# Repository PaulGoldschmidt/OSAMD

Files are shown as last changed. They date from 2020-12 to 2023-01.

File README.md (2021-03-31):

# Wie man ein Luftqualitätssensor mit einem niedrigen Budget baut: Das OSAMD-Projekt
Hohe Luftqualität ist wichtig. Eigentlich schon immer, denn in besserer Luft kann man sich länger konzentrieren. Grade in der Schule ist das Thema doch jetzt wichtiger denn je, denn dank COVID-19 müssen in vielen Schulen Deutschlands regelmäßig Lüftungspausen eingelegt werden. Was ansich gut ist, wird im Winter von Tag zu Tag schwieriger umzusetzen: Das kalte Klima und die Heizungen im Klassenzimmer führen so täglich einen Kampf um die Lufttemperatur, bei der die Heizung nur unter erheblicher Wärmeabgabe die Luft aufwärmen kann, was zu enormen Steigerungen der Heizungskosten und einem erhöhtem CO2-Ausstoß führt.

Deshalb habe ich mich dafür entschlossen, ein Luftqualitätsmessgerät zu entwickeln, welches mit niedrigen Teilkosten (circa 7-10 Euro/Einheit) die Luft in Klassenzimmern überwachen kann und eine Warnung abgibt, wenn die Luftqualität kritisch schlecht ist. Der Name dieses Projekts, OSAMD, steht für "Open-Source Air-Monitoring Device", also eine quelloffene Lösung zur Überwachung der Luftqualität.
Eine Anleitung zum Selbstbau dieses Projekts liegt im Ordner "0_Documentation", die Hardwareteile im Ordner "1_Hardware" und die benötigte Software im Ordner "2_Software".

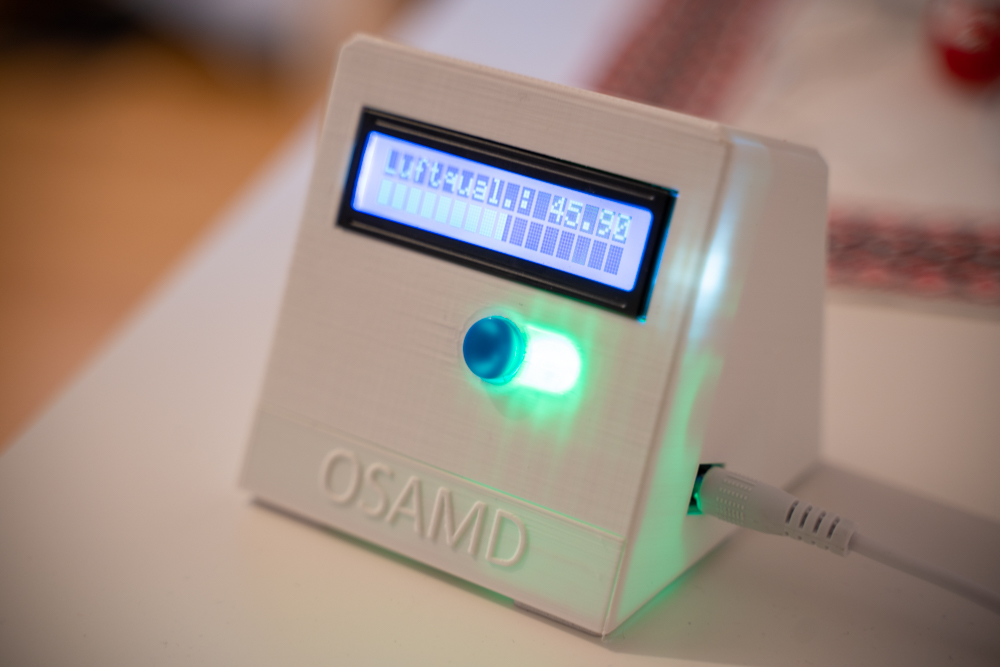
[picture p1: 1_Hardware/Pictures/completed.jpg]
Das fertige OSAMD-Projekt

[So wurde übrigens das Gehäuse designed](https://www.youtube.com/watch?v=d4DvKm7_OzI)

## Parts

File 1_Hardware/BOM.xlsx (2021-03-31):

BOM: OSAMD-Projekt
 | Teil Nr. | Bezeichnung | Teilnummer | Anzahl | Preis | Anmerkung | Link
 | 1 | Luftqualitätssensor | MQ-135 Module | 1 | 1.00 € |  | https://de.aliexpress.com/item/32905811669.html
 | 2 | Microcontroller | Arduino Nano | 1 | 1.60 € | Anschlusstyp ist nicht relevant, solange ein passendes Kabel vorhanden ist. (Ich empfehle Micro-USB) | https://de.aliexpress.com/item/32241679858.html
 | 3 | LCD-Display | 1602 LCD Display | 1 | 0.80 € | Es kann auch direkt ausgwählt werden, dass ein I2C-Wandler vorinstalliert werden soll. Dies spart Arbeit und Versandkosten. | https://de.aliexpress.com/item/32649621944.html
 | 4 | I2C-Wandler | PCF8574 | 1 | 0.50 € |  | https://de.aliexpress.com/item/32262710755.html
 | 5 | Knopf | 12x12x7 mm | 1 | 0.05 € | Preis für 20 Stück unter 0,8 Euro | https://de.aliexpress.com/item/32912422770.html
 | 6 | RGB-LED | Common Anode RGB LED (5mm) | 1 | 0.03 € | Preis für 100 Stück circa 3 Euro | https://de.aliexpress.com/item/32686524860.html
 | 7 | Stromanschluss | DC-005C-25A | 1 | 0.25 € |  | https://lcsc.com/product-detail/AC-DC-Power-Plugs-Receptacles_Korean-Hroparts-Elec-DC-005C-25A_C223903.html
 | 8 | Lautsprecher/Buzzer | 5V Piezo Summer | 1 | 0.10 € | Preis für 10 Stück unter einem Euro | https://de.aliexpress.com/item/32914327679.html
 | 9 | Widerstand 10 kOhm | 1/4 Watt Metallfilm | 2 | 0.01 € | Preis für 100 Stück circa 0,7 Euro | https://de.aliexpress.com/item/32315929780.html
 | 10 | Widerstand 180 Ohm | 1/4 Watt Metallfilm | 1 | 0.01 € | Preis für 100 Stück circa 0,7 Euro | https://de.aliexpress.com/item/32317099861.html
 | 11 | Widerstand 130 Ohm | 1/4 Watt Metallfilm | 1 | 0.01 € | Preis für 100 Stück circa 0,4 Euro | https://de.aliexpress.com/item/1005001649125832.html
 | 12 | Widerstand 120 Ohm | 1/4 Watt Metallfilm | 1 | 0.01 € | Preis für 100 Stück circa 0,7 Euro | https://de.aliexpress.com/item/32577107532.html
 | 13 | Leiterplatte | 1,6 mm, 2 Layer 85 * 70 mm FR4 PCB | 1 | 0.34 € | Preis für 5 Stück 1,69 Euro | https://jlcpcb.com/order
 | 14 | Stromkabel | USB zu DC 5,5 * 2,5mm Stromkabel | 1 | 0.83 € | Es gibt verschiende Längen und unterschiedliche Kabelfarben zur Auswahl, solange der Anschluss passt, ist diese Auswahl egal. | https://de.aliexpress.com/item/4000993209004.html
 | 15 | Versandpauschale | - | - | 4.00 € | - | -
 |  | ZUSAMMEN |  |  | 9.54 €
 | Hinweise: | Allgemein lohnt es sich, die Teile zu Vergleichen und zu schauen, wer zur Zeit die besten Teilpreise liefert.
 |  | Auch Sammelbestellungen lohnen sich sehr, so schafft man niedrigere Gesamtpreise und spart Versandkosten und CO2-Emissionen.

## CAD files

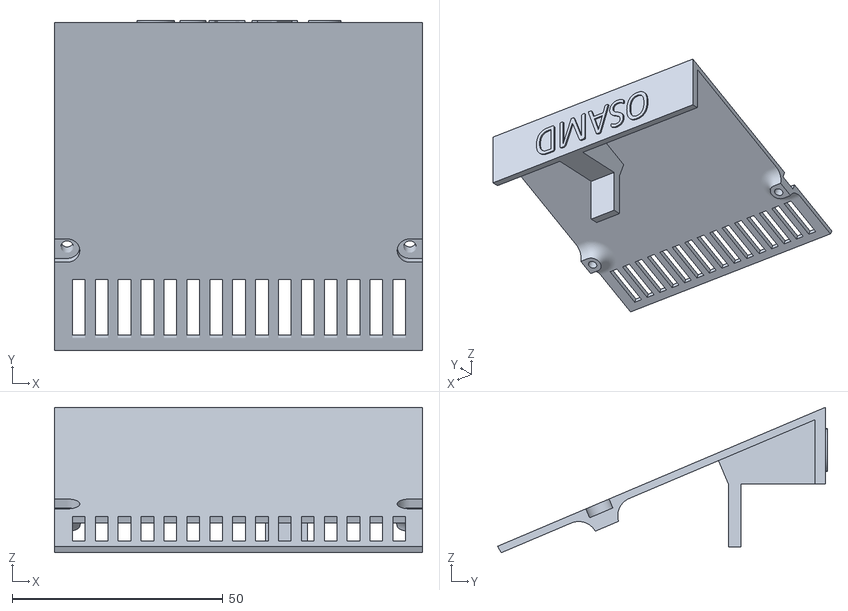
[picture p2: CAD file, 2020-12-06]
1_Hardware/Enclosure/Enclosure_PART-B.stl
87.2 x 78.2 x 34.5

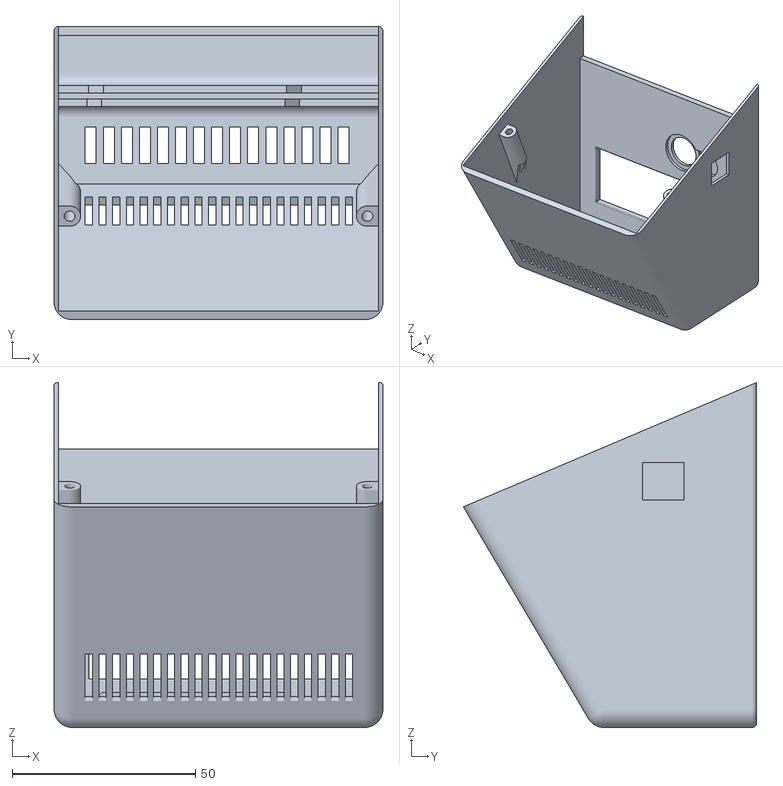
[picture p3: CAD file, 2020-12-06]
1_Hardware/Enclosure/Enclosure_PART-A.stl
89.8 x 80.1 x 94.2

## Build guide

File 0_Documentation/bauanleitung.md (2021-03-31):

# Wie man OSAMD bauen kann: Eine kleine Anleitung :bulb:
In diesem Dokument wird gezeigt, wie man sich die Luftqualitätsmessstation selber bauen kann. Viel Spaß beim bauen!
## Schritt 1: Vorbereitungen
Bevor mit dem Bauen begonnen wird, sollte sichergestellt werden, dass alle Teile und Werkzeuge zur Verfügung stehen.
Eine Materialliste (BOM, Bill of Materials) lässt sich [hier finden.](https://github.com/PaulGoldschmidt/OSAMD/blob/main/1_Hardware/BOM.xlsx)
Werkzeuge, die benötigt werden:
 1. Lötkolben
 2. kleiner Seitenschneider
 3. Verbauchsmaterialien ((bleifreies) Lötzinn, Kabel und Entlötlitze sowie zwei M3 Gewindeschrauben mit mindestens 15 mm länge)
Sonst wird noch der Zugriff auf einen PC und auf einen 3D-Drucker benötigt. 3D-Drucker lassen sich vielen öffentlichen Makerspaces finden, der Druck des Gehäuses dauert rund 10 Stunden. Abstandshalter aus Messing helfen und sorgen dafür, dass die Teile immer im richtigen Platz bleiben.
Ein aufgeräumter Werktisch ist auch nur empfehlenswert.
## Schritt 2: 3D-Drucken!
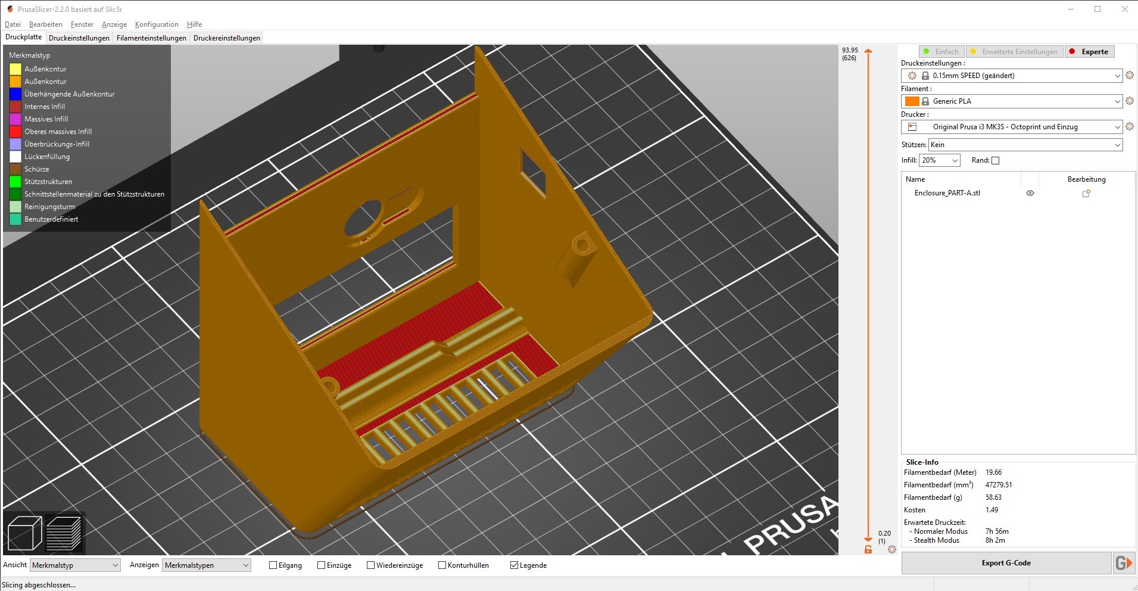
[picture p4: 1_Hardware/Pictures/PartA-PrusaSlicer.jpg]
Teil A des Gehäuses im Slicer.
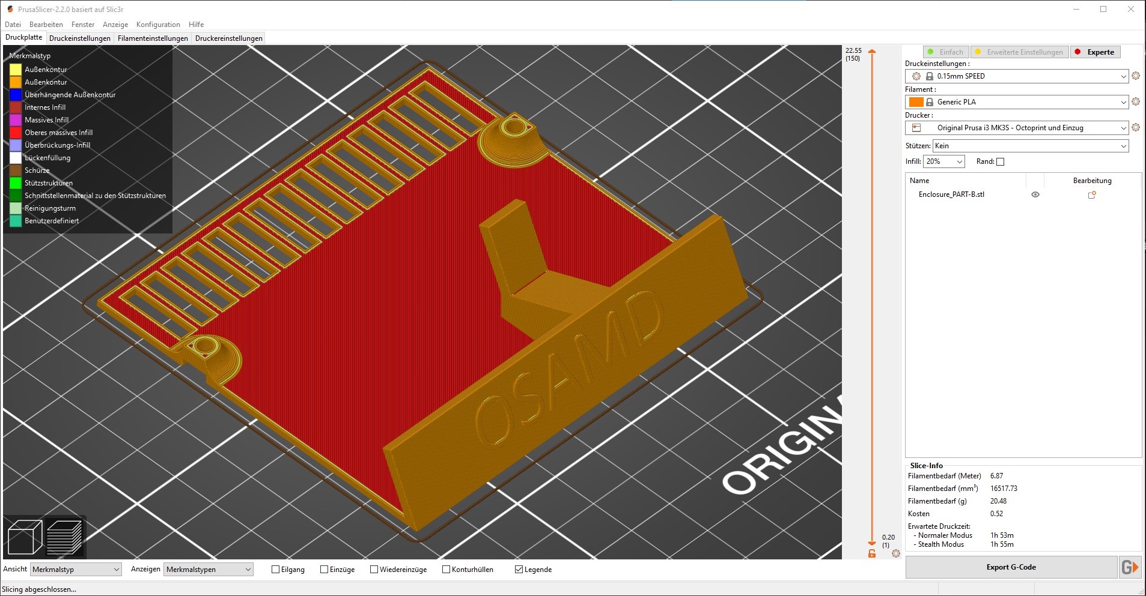
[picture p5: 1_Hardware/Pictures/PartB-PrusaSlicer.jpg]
Teil B des Gehäuses im Slicer.
Als erstes sollte der Druck des Gehäuses angestoßen werden, da dieser am längsten dauert. Unter [1_Hardware/Enclosure](https://github.com/PaulGoldschmidt/OSAMD/tree/main/1_Hardware/Enclosure) finden sich die 3D-Modelldateien, die gedruckt werden sollten. Ich habe die Teile mit Mattweißen PLA und 150 μm Schichtdicke auf einem Prusa i3 MK3S gedruckt, beim Teil A empfiehlt es sich je nach Drucker supportmaterial hinzuzufügen.
Die Knopfverlängerung sollte auch jetzt schon gedruckt werden, die Druckzeit beträgt jedoch nur 5 Minuten.
Nachdem die Teile geruckt sind, geht es zum
## Schritt 3: Den Microcontroller vorbereiten :floppy_disk:
Als nächstes wird die Firmware auf den Microcontroller gespielt. Dafür wird der Arduino mit einem PC verbunden, auf dem die Arduino-IDE installiert ist. Dann kann nach öffnen des Sketches in der IDE und dem Auswählen des Seriellen Ports, an dem der Arduino angeschlossen ist, der richtige Chip ausgewählt werden. "Arduino Nano / Old Bootloader" empfiehlt sich hier, da die meisten Arduinos heutzutage noch den alten Bootloader verwenden (Optiboot ist der neue).
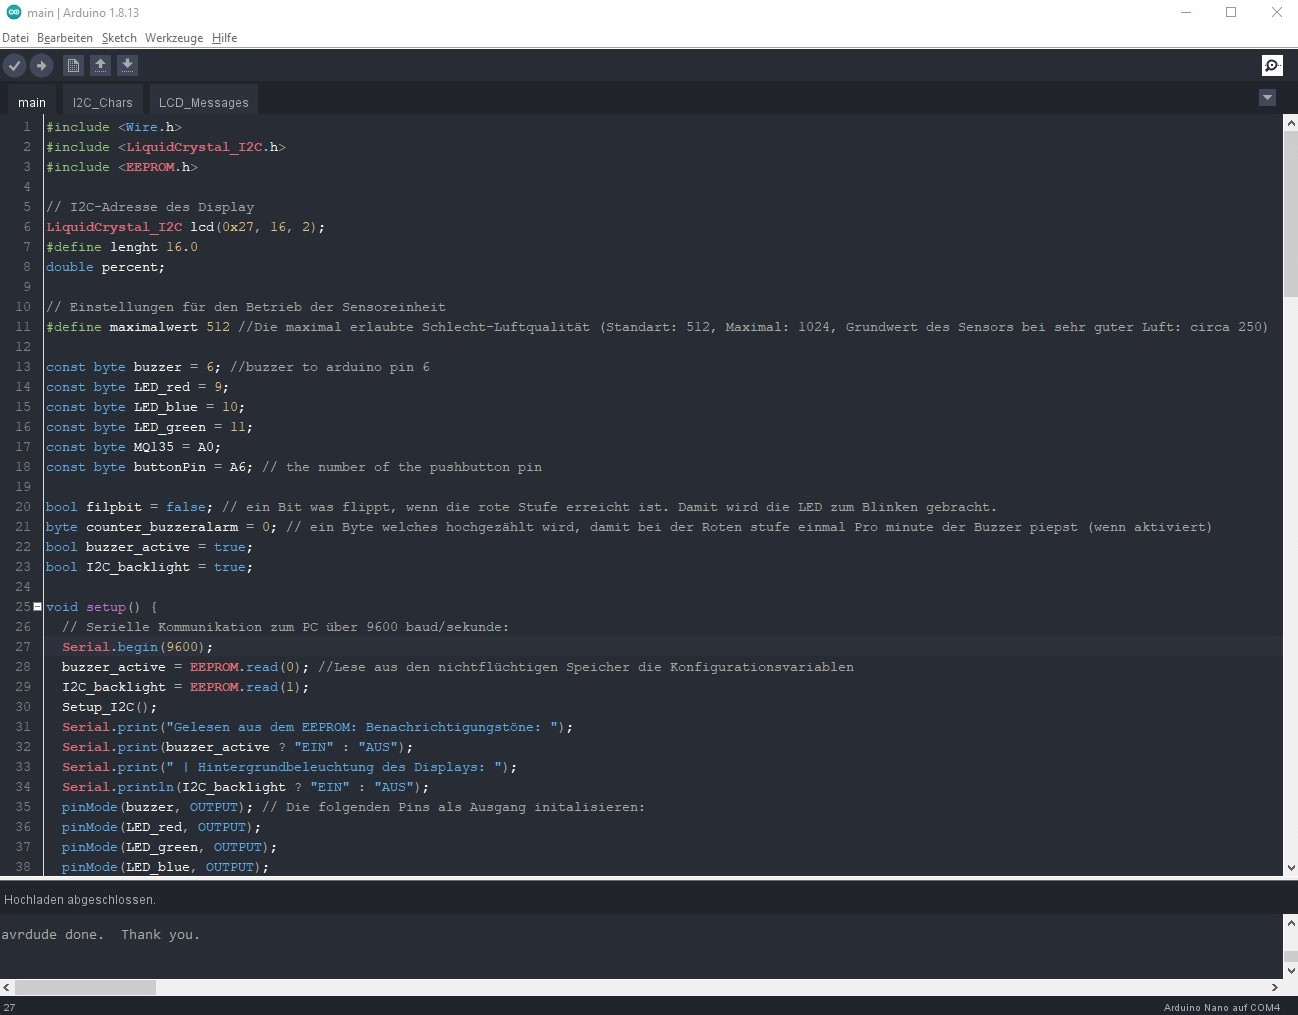
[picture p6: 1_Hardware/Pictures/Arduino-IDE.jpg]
Die Arduino IDE mit geöfnetem Hauptprogramm
Wenn die firmeware aufgespielt ist, kann der serielle Monitor (@9600 Baud) geöffnet werden. Hier sollte jetzt stehen, dass der Sensor aufheizt. Wenn das passiert, kann der Arduino abgezogen werden und es kann mit dem eigentlichen Zusammenbau los gehen.
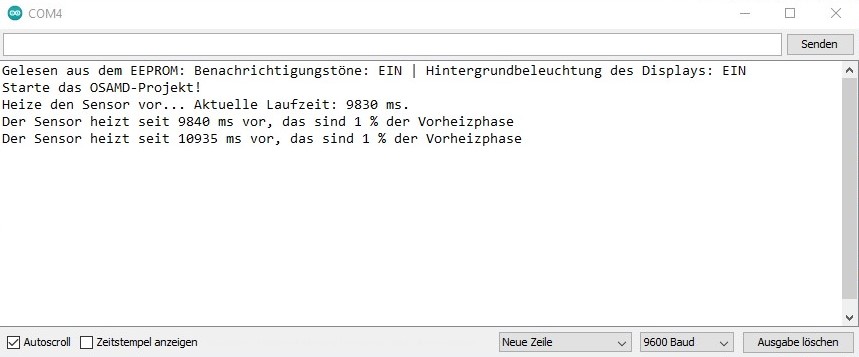
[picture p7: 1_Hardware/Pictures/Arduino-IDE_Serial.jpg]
Die Serielle Konsole gibt was aus, sieht also gut aus!

## Schritt 4: Das Löten
Nun kann es aber richtig lösgehen:
Erstmal die Widerstände in die Plätze setzen, dann diese einlöten. Die verbleibenden Litzen abschneiden, dann weiter den Schalter einlöten. Beim Arduino die Stiftleiten einlöten und auf das PCB löten (Wer nurmal sicher gehen will, kann einfach zwischen den Maleheader des Arduinos einen female-header setzen und so beim (unwahrscheinlichen) Kaputtgehen des Arduinos eine leichte austauschmöglichkeit schaffen.
Bevor das LCD-Panel und der Sensor eingelötet wird, muss noch der Kontrast vom LCD-Panel richtig eingestellt werden.
Nachdem noch der Buzzer eingelötet wurde, kann zu den beiden Submodulen gegangen werden: Bei diesen erst die voreingebauten Stiftleisten um 90 Grad drehen, sodass diese in die Vorrichtung auf dem PCB passen. Dann die Messing-Spacer in die Löcher stecken, die Module festschrauben und zu guter letzt die Verbindungen löten. So sieht das Mainboard dann aus:
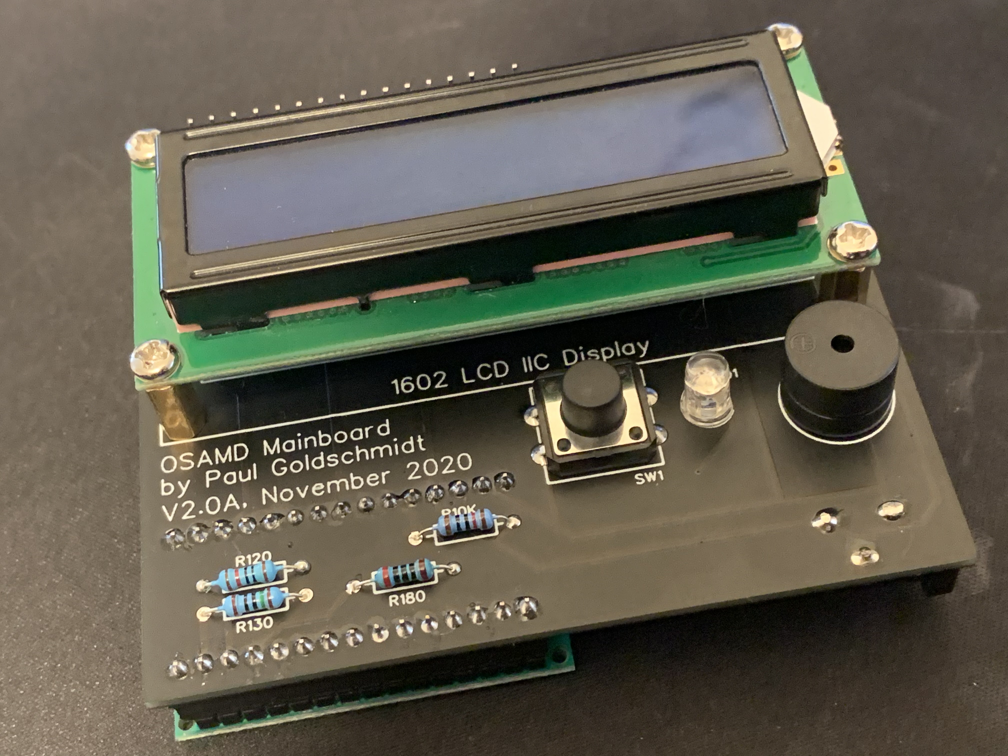
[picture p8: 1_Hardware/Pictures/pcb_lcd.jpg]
So sieht das Mainboard dann aus

Und die Unterseite (auf dem Bild ist noch ein rotes Jumperkabel zu sehen, dieses ist in der aktuellen Hardwareversion nicht mehr benötigt):
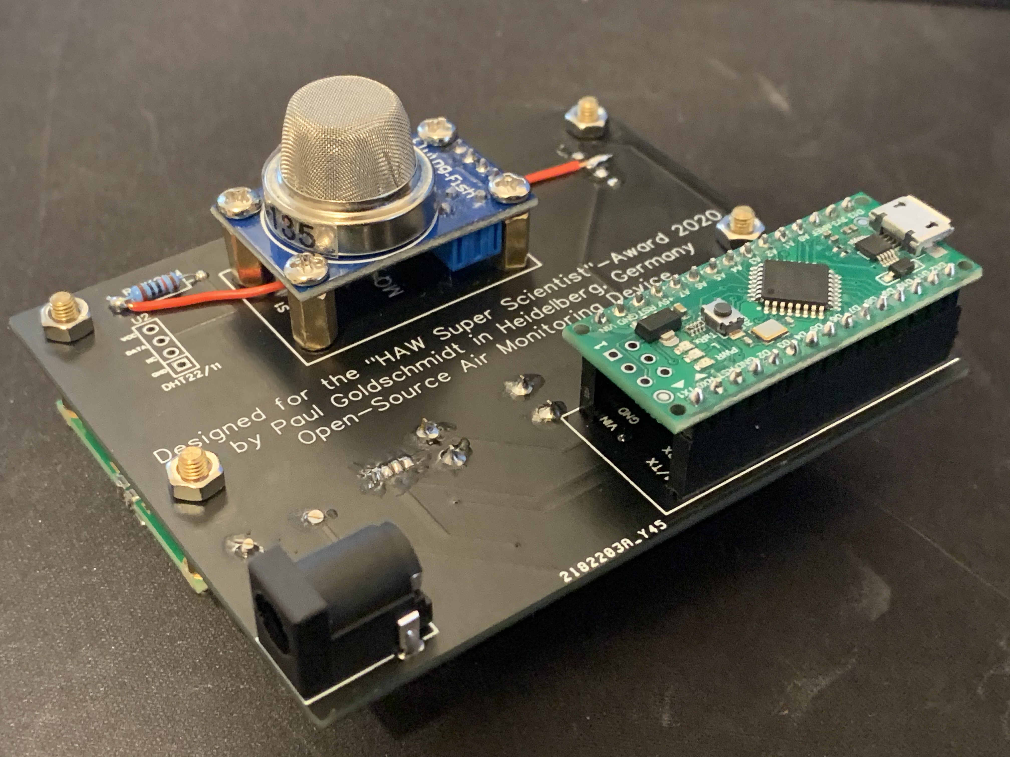
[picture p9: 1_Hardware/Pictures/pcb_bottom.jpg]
Die Unterseite des PCBs

Bevor nun das Projekt zusammengeschraubt wird, kann dem gesamten Aufbau ein erster Funktionstest unterzogen werden. Dafür einfach das Stromkabel einstecken und auf der anderen Seite in ein USB-Netzteil stecken, dann sollte das folgende passieren:
Das LCD-Panel geht an, die LED leuchtet grün, blau und dann weiß, bevor sie rot wird und auf dem LCD-Display "Vorwärmen" steht.
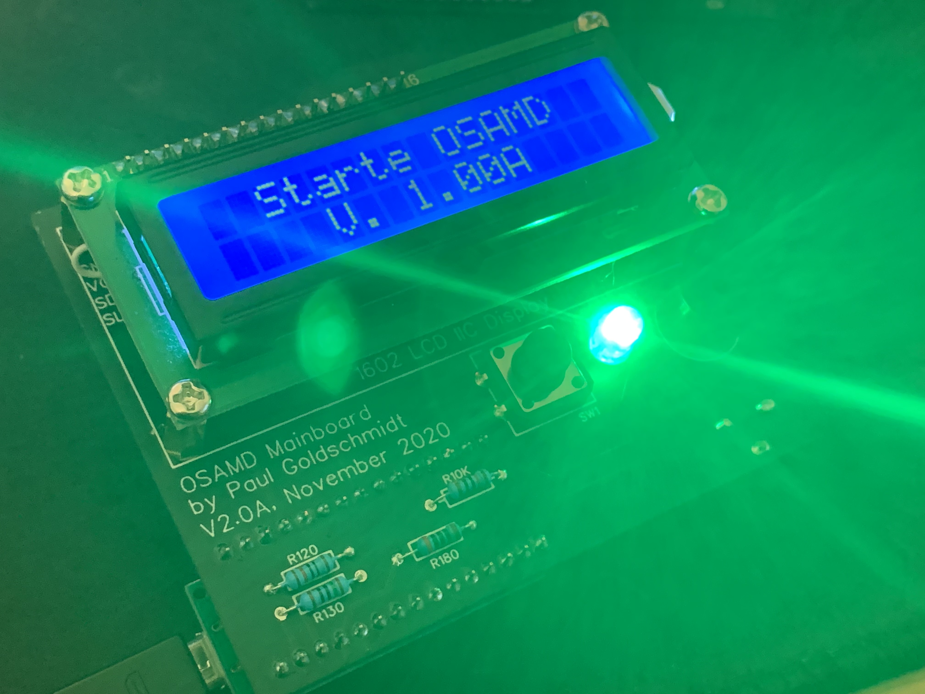
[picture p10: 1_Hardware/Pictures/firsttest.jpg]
Es funktioniert!

Wenn das alles passt, kann der Zusammenbau beginnen.
## Schritt 5: Der finale Zusammenbau
So, da jetzt alles funktioniert, kann das Projekt endlich zusammengebaut werden. Als erstes wird der Knopf mit der 3D-Gedruckten Verlängerung ausgestattet:
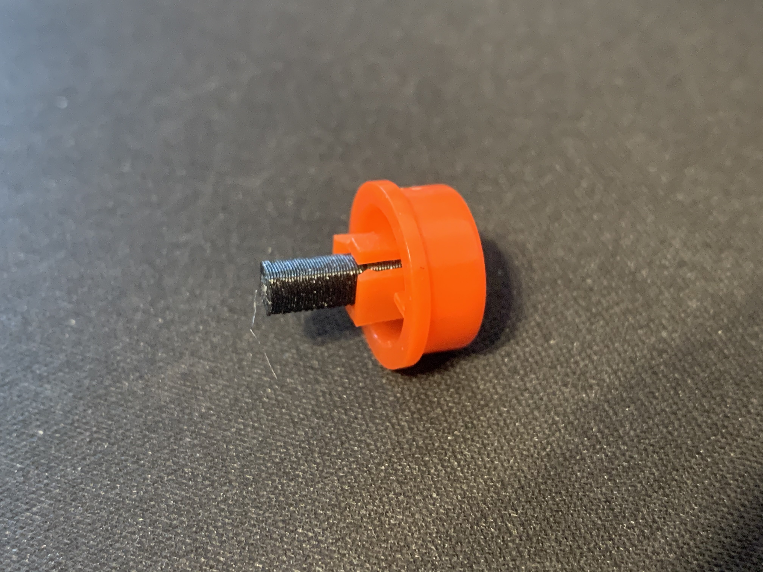
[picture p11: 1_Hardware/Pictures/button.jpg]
Der Knopf mit der 3D-Gedruckten Verlängerung

Als nächstes wird der Knopf in das Gehäuse gesteckt, dann wird das PCB in den Slot oben im Gehäuse geschoben, sodass das dann so aussieht:
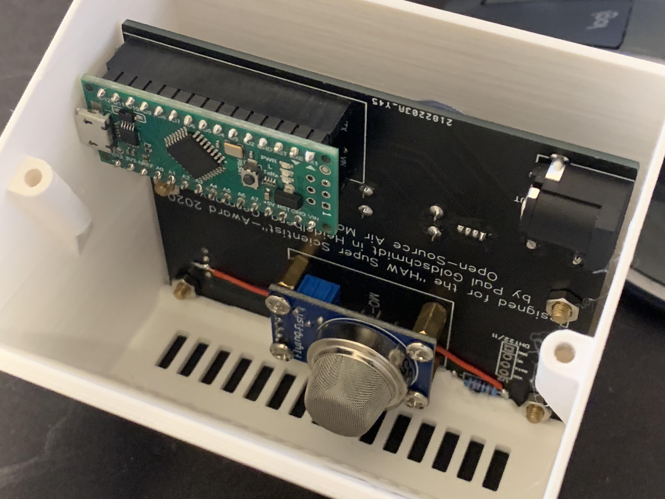
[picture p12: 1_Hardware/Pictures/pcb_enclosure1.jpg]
Der Knopf mit dem PCB im Gehäuse

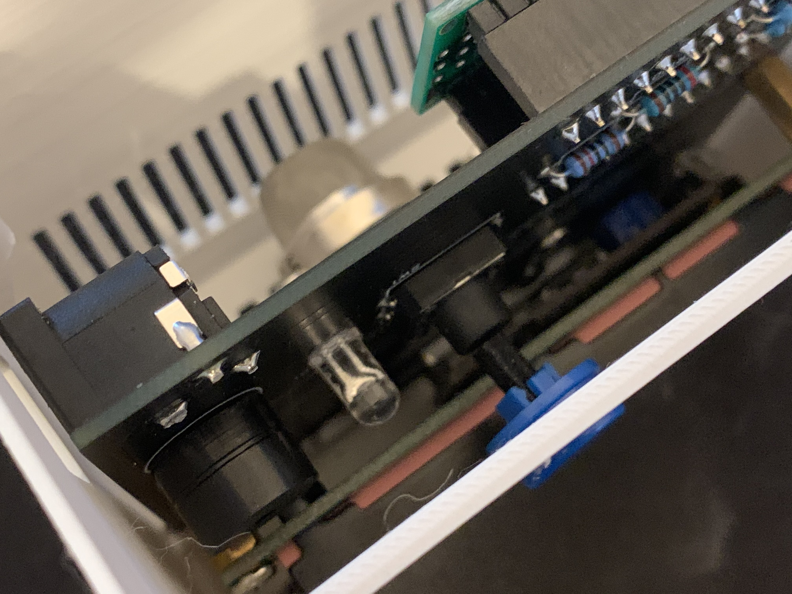
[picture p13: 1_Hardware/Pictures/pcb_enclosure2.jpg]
und noch von der anderen Seite

Dann kann die Unterseite auch in das Gehäuse geschoben werden:
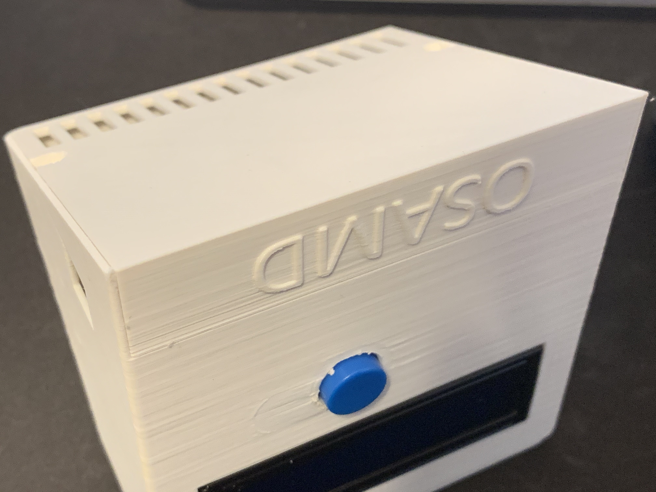
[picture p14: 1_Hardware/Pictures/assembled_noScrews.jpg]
die Unterseite an dem Gehäuse

Als nächstes wird dass alles verschraubt:
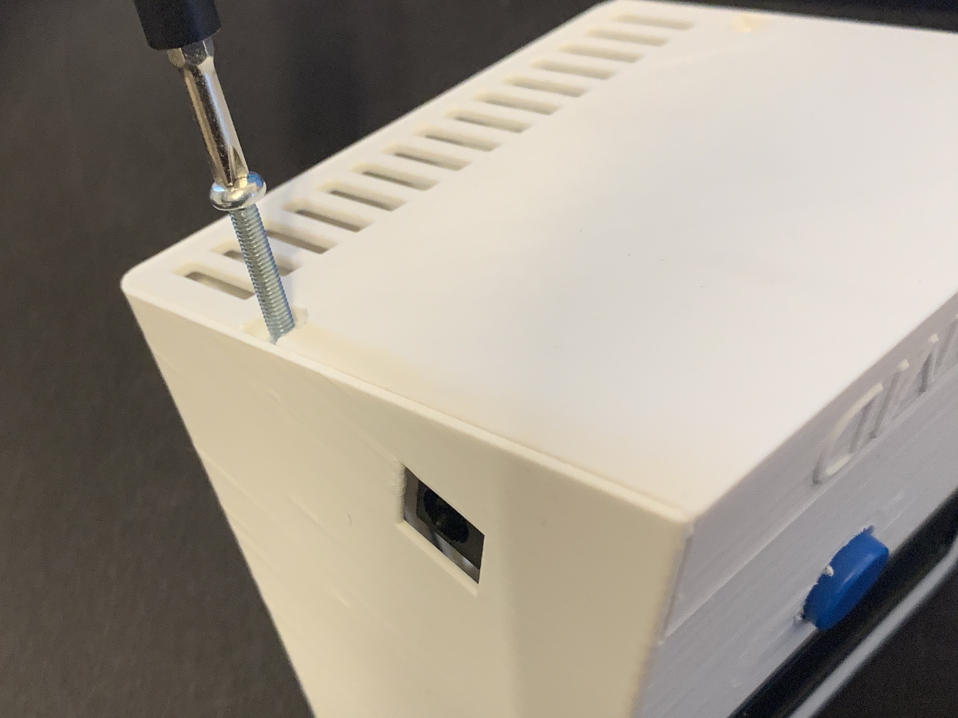
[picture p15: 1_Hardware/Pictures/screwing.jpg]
Und die Schrauben rein!

Dann sieht das von unten so aus:
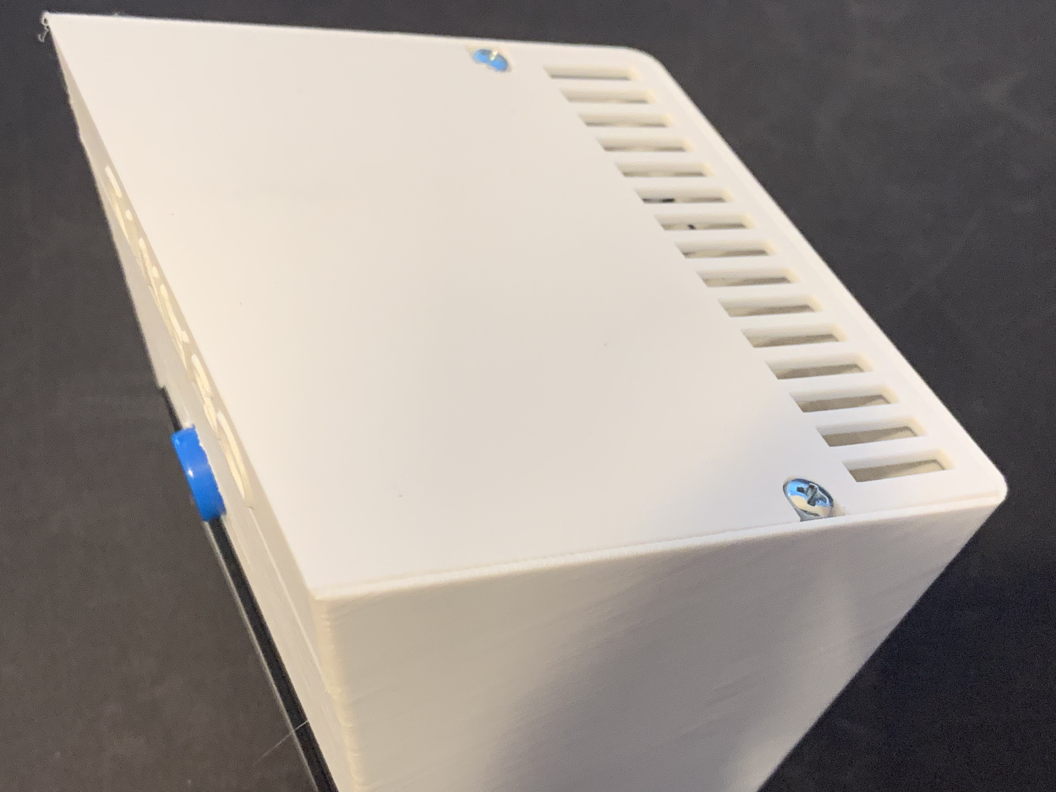
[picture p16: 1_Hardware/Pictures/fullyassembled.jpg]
Die Sicht von unten

Damit Luft von unten rein kann und das Gehäuse gut steht, werden kleine Füße an das Gehäuse geklebt (und auch über die Schrauben
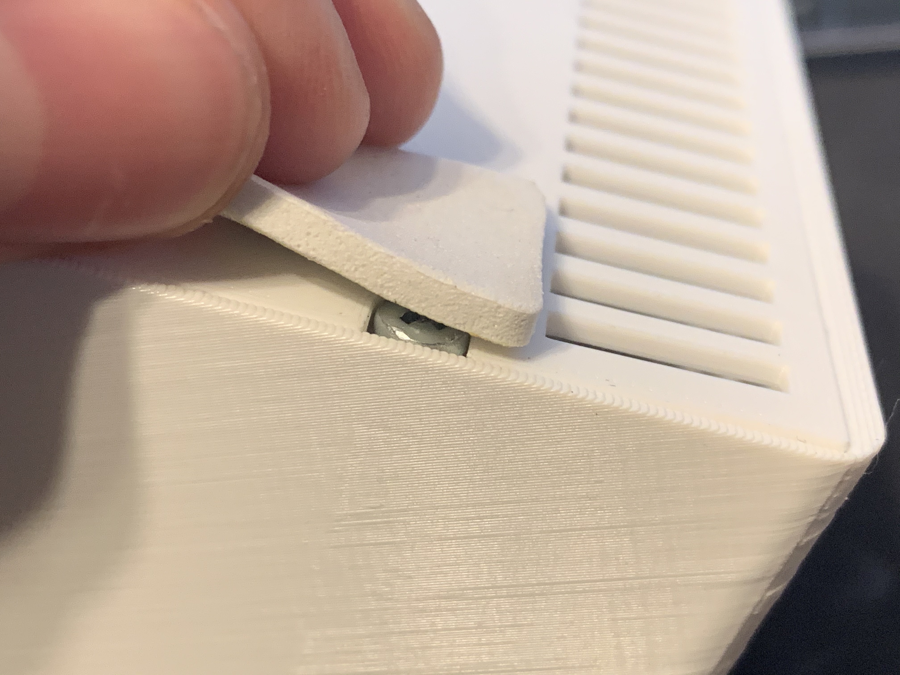
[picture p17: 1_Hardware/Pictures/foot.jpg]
Füße über die Schrauben

Mit allen Füßen sieht dass dann so aus:
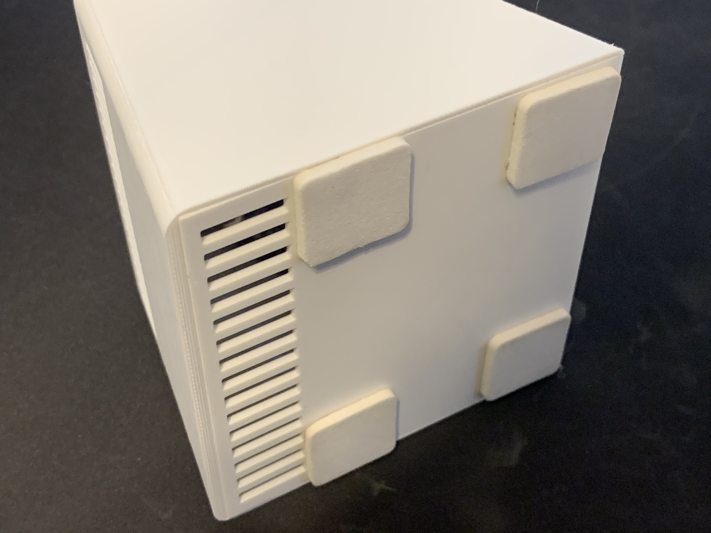
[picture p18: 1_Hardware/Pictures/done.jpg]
Das fertige Gehäuse von unten

Dann kann das Projekt eingesteckt werden, und sollte alles wie gewünscht Funktionieren: **Herzlichen Glückwunsch! :tada:**
Das fertige Projekt

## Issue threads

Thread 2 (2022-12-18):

Anpassung an ESP8266 / ESP32

silen72, 2022-12-18:
Hallo @PaulGoldschmidt, ich würde das Projekt gerne an ESP8266 / EPS32 anpassen, damit ich die gemessenen Werte an einen MQTT-Server senden kann. Dafür müsste ich natürlich auch die Platine anpassen. Wäre es möglich, die Ursprungsdateien für die Platine (und ggf. auch für das Gehäuse) ebenfalls zu veröffentlichen?

PaulGoldschmidt, 2022-12-21:
Hallo @silen72!
Super cool, gerne stelle ich alle Quelldateien zu Verfügung - welches Format würde dir passen? Nativ habe ich die vor fast drei Jahren in EasyEDA erstellt, würde mich aber auch sonst um ein Eagle/KiCAD-Datenstack kümmern.

Viele Grüße,
Paul

silen72, 2023-01-01:
Hallo Paul,
ich habe für Schaltungen und Platinen bisher immer KiCAD verwendet, das wäre daher für mich perfekt. Mach Dir bitte keine Mühe, das zu konvertieren. Erster Treffer in Google: [wokwi easyeda2kicad](https://wokwi.com/tools/easyeda2kicad), das kriege ich hin :-)
Bei 3D-Dateien bin ich ziemlich blutiger Laie - da kenne ich nur TinkerCAD. Vielen Dank für Deine Bereitschaft, die Quelldateien zu teilen! Für meine Anpassungen werde ich einen Fork Deines Repos anlegen und wenn ich soweit bin, einen pull request erstellen.

Gruß
Niels

PaulGoldschmidt, 2023-01-06:
Hallo Niels,

ich habe mit dem letzten Commit alle sourcefiles in verschiedenen Formaten hochgeladen. Schau am besten mal rein und melde dich, wenn du noch weitere Infos/Hilfe benötigst.

Herzliche Grüße,
Paul

silen72, 2023-01-07:
Hallo Paul,

vielen Dank, damit kann ich schon mal die exakten Maße der Platine und die Positionen von Sensoren und Aktoren auf der Platine feststellen. Magst Du auch noch die Schaltung teilen (Schematic)? Das würde es mir erleichtern, die Punkte zu erkennen, an denen ich ansetzen muss, um den Nano mit einem ESP zu ersetzen (u.a. verträgt der ESP maximal 3.3V an seinen Eingängen). Falls nicht ist das auch ok, ich finde dann die notwendigen Infos per reverse engineering.

Danke und Gruß
Niels

PaulGoldschmidt, 2023-01-07:
Moin Niels,

suche ich heraus, weiß aber tatsächlich nicht, wie aktuell der noch ist, da das Projekt leider (wie man merkt) an vielen stellen mit enormem Zeitdruck entwickelt wurde (z.B. der etwas komische Sprachenmix) - zu dem 3,3V spannungslevel: du müsstest wahrscheinlich level-shifting oder einen Spannungsteiler vor den analogeingang des ESPs spannen, der Sensor arbeitet leider nur mit 5V laut [Datenblatt](https://www.olimex.com/Products/Components/Sensors/Gas/SNS-MQ135/resources/SNS-MQ135.pdf). Theoretisch könnte man aber auch mal testen, wie der auf 3,3 Volt reagiert, ggf. müsste nur die Range der Ausgangsspannung angepasst werden.
Wie sehr hast du vor, die Teile integriert zu bauen? Oder anders gefragt: Hast du vor, ein ESP-Devboard (NodeMCU, etc.) zu nehmen, oder willst du den komplett in Modul- oder Chipweise auf die Leiterplatte bringen? Devboards haben zumindest als secondary spannungslevel 5V, da kann man dann den Sensor mit treiben, dann noch zwei Widerstände und der Spannungsteiler sitzt.
Die LCDs gibt es auch mit 3,3V als Level für die Hintergrundbeleuchtung, LEDs brauchen andere Widerstände, der Buzzer müsste auch einfach mit 3,3V als Zielspannung bestellt werden.

Viele Grüße,
Paul

silen72, 2023-01-08:
Ich würde gerne Deiner Philosophie folgen, dass das Board auf jeden Fall auch mit kleinem Aufwand und einfachen Werkzeugen herstellbar ist (also THT statt SMD, eher Devboard als alles integriert, eher Spannungsteiler als level shifter). Einer höher integrierten Platine steht dann nichts im Weg, die kann ich in KiCad ja leicht zusätzlich aus der Schaltung erzeugen.
All die Dinge, die Du ansprichst, muss ich mir anschauen und damit experimentieren. Dabei würde mir Deine Schaltung Zeit sparen, selbst wenn es nicht mehr exakt zur Platine passt. Ich habe das reverse engineering sowieso schon angefangen, falls Du noch was findest, kann es nur helfen. Falls nicht eben nicht ;-)

silen72, 2023-04-28:
Hallo @PaulGoldschmidt, ich mache Fortschritte. Den Code musste ich leider massiv ändern, weil ich für die MQTT-Anbindung WLAN benötige. Und bei WLAN darf der Code im loop() nicht lange dauern, daher sollte er keine delay()-Aufrufe enthalten. Folglich habe ich alles auf non-blocking umgeschrieben. Falls Du Interesse hast, ich habe [hier eine Simulation für ESP32 ](https://wokwi.com/projects/363144454759988225) erstellt.

Zudem habe ich den Code erfolgreich mit einem D1 mini lite (ESP8266) in Hardware getestet. Ich muss jetzt noch ein paar Kanten rund schleifen, dann checke ich den Code wieder [in meinem Fork-Repo](https://github.com/silen72/OSAMD) ein.

Da ich keinen Arduino Nano besitze: kannst/magst Du es dann mal auf Deinem Board testen?

silen72, 2023-08-23:
Hallo @PaulGoldschmidt, nachdem die Hardware (ESP8266) auf dem Breadboard schon mal ihre Funktion bewiesen hatte, habe ich jetzt auch erfolgreich einen Prototypen auf einer angepassten Platine laufen.

Um die Positionierung der Bauteile prüfen zu können, habe ich mir daher das Gehäuse einmal drucken lassen. Dabei musste ich feststellen, dass bei Deinen STL-Dateien nur die Gehäuse-Schale und der Boden zu finden sind - der Knopf und dessen Verlängerung fehlen. Hast Du den orangenen / blauen Knopf gekauft oder selbst gedruckt? => Kannst Du bitte die BOM und/oder die STL-Dateien entsprechend ergänzen?

Zudem habe ich keine Angaben zu den Längen der Messing-Abstandshalter gefunden. Ich habe ein Set Abstandshalter, aus dem habe ich für das LCD 10mm lange gewählt, damit passt das LCD perfekt in die Aussparung. Vielleicht magst Du ja Deine Anleitung entsprechend ergänzen? Dito für den MQ-135.

Apropos Anleitung ergänzen: Du schreibst für das Einbauen der Submodule: "Bei diesen erst die voreingebauten Stiftleisten um 90 Grad drehen, sodass diese in die Vorrichtung auf dem PCB passen." Zum einen musste ich die LCD-Ansteuerungsplatine selbst an das LCD löten und zum anderen VORHER die 90°-Pins der Ansteuerungsplatine auslöten und gegen senkrechte ersetzen (BOM?). Das wäre nach dem Zusammenlöten von LCD und Ansteuerungsplatine nicht mehr möglich gewesen.

PaulGoldschmidt, 2023-09-01:
Moin @silen72!
Entschuldige meine späte, späte Antwort - freue mich total dein Update zu lesen, wir hatten in dem Projekt viele Workshops und parallel weitere Projekte in der Entwicklung, deswegen habe ich heute das erste mal seit Monaten in das Entwicklungs-Repo hier hereingeschaut.
Ich plane, kommende Woche die ganzen Updates aus Lokalgruppen, die nicht in dem Repo gespiegelt sind, hier einzubauen. Dabei schaue ich auch nochmal durch all deine Punkte durch und ergänze im Repo wo nötig.

Danke schonmal für deine Arbeit, super super cool und viele Grüße,
Paul

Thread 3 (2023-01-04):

Hinzufügen von Support für DHT22 & DHT11-Temperatursonden

PaulGoldschmidt, 2023-01-04:
Es wäre toll, Temperatur- und Luftfeuchtigkeitssonden (DHT11/DHT22) softwaretechnisch zu implementieren. Dann kann neben der allgemeinen Luftqualität im Raum auch die Luftfeuchte und Temperatur angezeigt werden.

PaulGoldschmidt, 2023-01-04:
Wurde hinzugefügt, in der Softwareversion 1.2 (siehe [releases](https://github.com/PaulGoldschmidt/OSAMD/releases/tag/V1.2)) sind nun DHT22 und DHT11-Sensoren unterstützt. In einem weiteren Issue (siehe #4) geht es darum, die Daten nicht nur anzuzueigen, sondern auch für eine bessere Lüftungsempfehlung heranzuziehen.

Closed 2023-01-04.

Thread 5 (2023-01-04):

Bestimmung des LQI über MQ135-Sensoren

PaulGoldschmidt, 2023-01-04:
Die aktuell verwendete Skala von 100 bis 0 funktioniert zwar und tut ihren Job, jedoch wäre eine annäherung der Messwerte an das LQI-System interessant.

Da dies mit dem verwendeten Sensor ein bisher nicht versuchtes unterfangen ist, müsste eine Menge forschungsarbeit in die Implementierung fließen, um die Werte des Sensors so zu mappen, dass diese in etwa der LQI-Skala (siehe [Kurzzeit-Luftqualitätsindex](https://www.umwelt.niedersachsen.de/assets/image/736/8855)) entsprechen.
Es ist desweiteren vollkommen klar, dass der Sensoraufbau aufbau des Messprinzips niemals in der Lage seien wird, akkurat und wiederholbar den LQI zu messen.

PaulGoldschmidt, 2023-01-15:
Es wurde über die Libary ["MQ Sensor Lib"](https://github.com/miguel5612/MQSensorsLib) bereits doch einiges schon an vorarbeit geleistet, ein erster Test hat aber leider auch gezeigt, das diese Libary - auch wenn das in den examples so dargestellt wird - nicht wirklich mit DHT-Messungen arbeiten kann, zudem muss die Kalibrationsroutine als Menüpunkt eingebaut werden, da diese bei jedem Start aufzurufen nicht sinnvoll ist in diesem Projekt.
Alles in allem ein haufen arbeit, ich habe im dem Branch [DirectCO2-Measure](https://github.com/PaulGoldschmidt/OSAMD/tree/DirectCO2-Measure) mit der Entwicklungsarbeit an diesem Thema angefangen. Updates folgen.

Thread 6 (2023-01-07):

Kleinigkeit: Typo in der Beschreibung

silen72, 2023-01-07:
Du hast "A project by Paul Goldschmidt to meaure the quality of air indoors" geschrieben. Das soll vermutlich "A project by Paul Goldschmidt to mea__**s**__ure the quality of air indoors" heißen.

PaulGoldschmidt, 2023-01-07:
Danke für den Tipp! Ist gefixed 🚀

Closed 2023-01-07.

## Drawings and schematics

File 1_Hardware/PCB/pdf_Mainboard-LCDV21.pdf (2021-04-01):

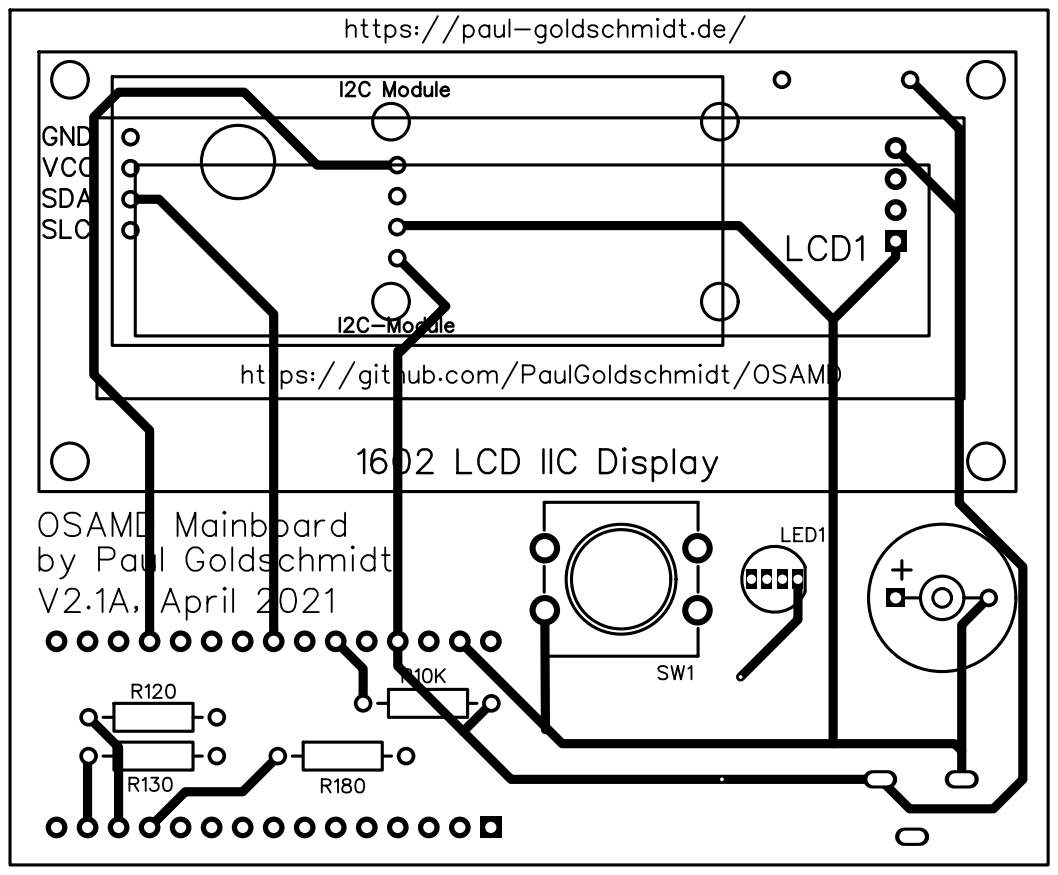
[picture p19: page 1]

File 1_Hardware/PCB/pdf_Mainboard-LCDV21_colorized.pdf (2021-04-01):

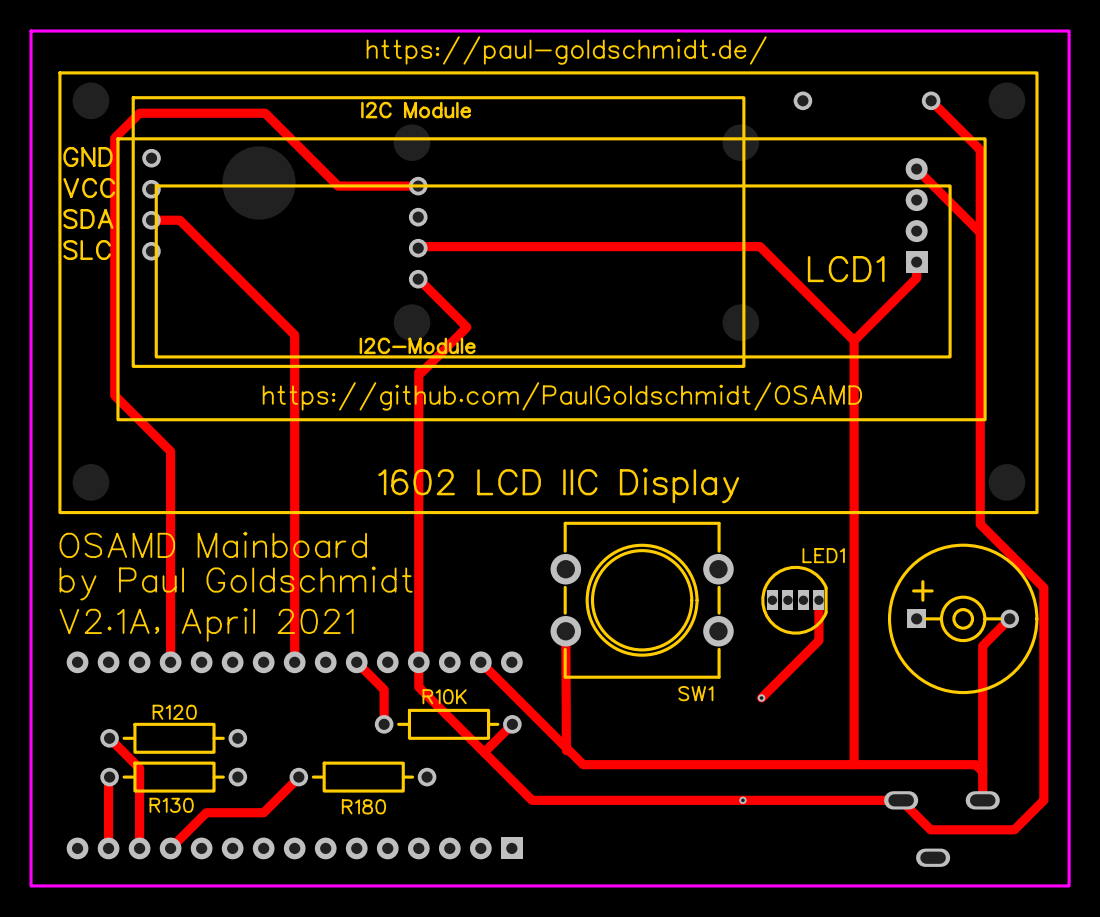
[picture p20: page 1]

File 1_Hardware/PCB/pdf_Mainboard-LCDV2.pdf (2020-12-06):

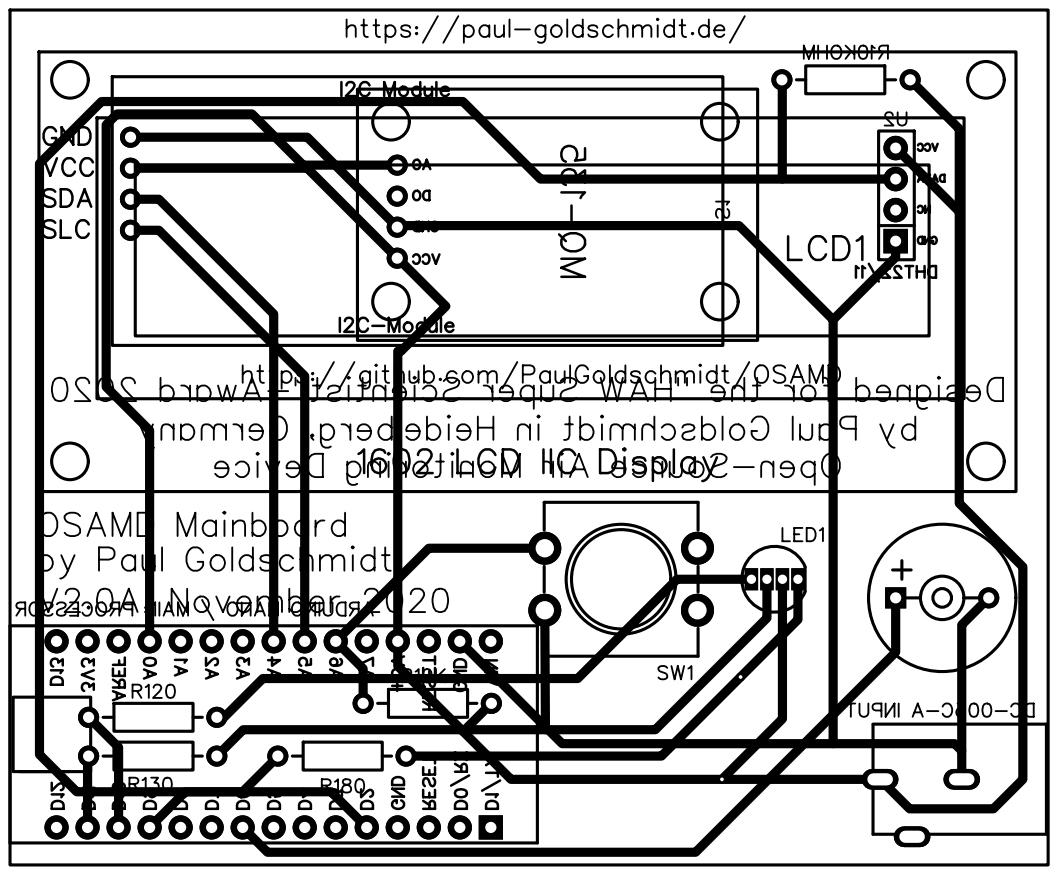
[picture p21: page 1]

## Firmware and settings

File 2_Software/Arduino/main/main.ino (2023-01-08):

#include <Wire.h>
#include <LiquidCrystal_I2C.h> // LiquidCrystal I2C - Frank de Brabander - Version 1.1.2
#include <EEPROM.h>
#define TEMPINSTALLED // auskommentieren, wenn kein DHT-Temperatursensor verwendet wird.

#ifdef TEMPINSTALLED
#include <DHT.h>
#define DHTPIN 2
#define DHTTYPE DHT11 //alternativ je nach verwendetem Sensor: DHT22 (auch (AM2302), AM2321) und DHT21
DHT dht(DHTPIN, DHTTYPE);
bool tempinfahrenheit = false; //bei true: Temperatur wird in Fahrenheit ausgegeben!
#endif

// I2C-Adresse des Display
LiquidCrystal_I2C lcd(0x27, 16, 2);
#define lengh 16.0
double percentDirty;

// Einstellungen für den Betrieb der Sensoreinheit
#define maximalwert 768 //Die maximal erlaubte Schlecht-Luftqualität (Standard: 512, Maximal: 1024, Grundwert des Sensors bei sehr guter Luft: circa 250)
//TODO: Aktive Kalibration des Sensors

const byte buzzer = 6; //buzzer to arduino pin 6
const byte LED_red = 9;
const byte LED_blue = 10;
const byte LED_green = 11;
const byte MQ135 = A0;
const byte buttonPin = A6; // the number of the pushbutton pin

bool filpbit = false; // ein Bit was flippt, wenn die rote Stufe erreicht ist. Damit wird die LED zum Blinken gebracht.
byte counter_buzzeralarm = 0; // ein Byte welches hochgezählt wird, damit bei der roten Stufe einmal Pro minute der Buzzer piepst (wenn aktiviert)
bool buzzer_active = true;
bool I2C_backlight = true;

void setup() {
  // Serielle Kommunikation zum PC über 9600 baud/sekunde:
  Serial.begin(9600);
  buzzer_active = EEPROM.read(0); //Lese aus den nichtflüchtigen Speicher die Konfigurationsvariablen
  I2C_backlight = EEPROM.read(1);
  Setup_I2C();
  Serial.print("Gelesen aus dem EEPROM: Benachrichtigungstöne: ");
  Serial.print(buzzer_active ? "EIN" : "AUS");
  Serial.print(" | Hintergrundbeleuchtung des Displays: ");
  Serial.println(I2C_backlight ? "EIN" : "AUS");
  pinMode(buzzer, OUTPUT); // Die folgenden Pins als Ausgang initalisieren:
  pinMode(LED_red, OUTPUT);
  pinMode(LED_green, OUTPUT);
  pinMode(LED_blue, OUTPUT);
  LED_off();
  #ifdef TEMPINSTALLED
  dht.begin();
  #endif
  if (buttonvalue() == false) {
    preheating();
  }
}

void loop() {
  bool displaytemp = false;
  float h;
  float t;
  #ifdef TEMPINSTALLED //wenn ein Temperatursensor installiert ist, dann wird hier die aktuelle Temperatur ausgelesen.
  h = dht.readHumidity();
  t = dht.readTemperature(tempinfahrenheit);
  if (isnan(h) || isnan(t)) {
    Serial.println(F("Konnte nicht vom Temperatursensor lesen."));
    displaytemp = false;
  }
  else {
    displaytemp = true;
  }
  #endif
  percentDirty = ((float)analogRead(A0) / (float)maximalwert) * 100; // Den Prozentwert des Maximalwertes
  float percentClean = 100 - percentDirty; //hier so, dass niedrigere Werte besser sind
  Serial.print("Aktuelle Luftqualität: ");
  Serial.print(analogRead(A0));
  Serial.print(", das entspricht ");
  Serial.print(percentClean);
  Serial.println(" %. ");
  Serial.print("Ein Temperatursensor wurde installiert: ");
  Serial.println(displaytemp ? "JA" : "NEIN");

  if (displaytemp) { //wenn Temperatur gelesen werden kann, dann dies im seriellen Monitor ausgeben.
    Serial.print(F("Humidity: "));
    Serial.print(h);
    Serial.print(F("%  Temperature: "));
    Serial.print(t);
    Serial.print(F("°C "));

    lcd.setCursor(0, 0);
    lcd.print("LQ: ");
    
    if (percentDirty <= 65) {
      lcd.print("GUT (");
    }

    else if ((percentDirty >= 65) && (percentDirty <= 75)) {
      lcd.print("WARN (");
    }

    else {
        lcd.print("L\365FTEN (");
    }
    lcd.print(round(percentClean));
    lcd.print(")");
    lcd.setCursor(0, 1);
    lcd.print("T: ");
    lcd.print(round(t));
    lcd.print((char)223);
    lcd.print("C | H: "); 
    lcd.print(round(h));
    lcd.print("%"); 
  } 

  else {
    lcd.setCursor(0, 0);
    lcd.print("Luftqual.: ");
    lcd.print(percentClean);
    LCD_Draw(percentClean);
  }

  int millis100pressed = 0; // Zählervariable für Knopfdruck initalisieren / zurücksetzen
  while (buttonvalue() == true) { //Wenn der Button gedrückt ist, wird in diese Funktion gegangen
    Serial.println("Knopf gedrückt!");
    millis100pressed++;
    delay(100);
    if (millis100pressed >= 30) {
      LED_off();
      LCD_Config();
      break;
    }
  }
  LED_off();
  if (percentDirty <= 65) {
    //bis 70% des Maximalwerts ist die Luftqualität gut
    digitalWrite(LED_green, LOW); //Damit ist die LED Grün
    Serial.println("Damit ist die Luftqualität im grünen Bereich.");
  }
  else if ((percentDirty >= 65) && (percentDirty <= 75)) {
    //jetzt sollte gelüftet werden, damit die LED Gelb
    digitalWrite(LED_green, LOW);
    digitalWrite(LED_red, LOW);
    Serial.println("Damit ist die Luftqualität im gelben Bereich.");
  }
  else {
    //die Luftqualität ist sehr schlecht, es sollte dringend gelüftet werden!
    if (filpbit == false) { //mit diesen Bedingungen binkt die LED
      digitalWrite(LED_red, LOW); //LED Rot
      filpbit = true;
    }
    else {
      digitalWrite(LED_red, HIGH);
      filpbit = false;
    }

    if ((counter_buzzeralarm >= 120) && (buzzer_active == true)) { //und hier wird ein mal pro minute der Buzzer aktiv, wenn eingeschaltet
      tone(buzzer, 440);
      delay(300);
      noTone(buzzer);
      delay(300);
      tone(buzzer, 440);
      delay(300);
      noTone(buzzer);
      counter_buzzeralarm = 0;
    }
    else if (buzzer_active == false) {
      counter_buzzeralarm = 0;
    }
    else counter_buzzeralarm++; //sonst hochzählen
    Serial.println("Damit ist die Luftqualität im roten Bereich.");
  }
  delay(500);
}

void preheating() { // Die Vorheizschleife
  bool skipPreheating = false;
  LCD_Startup();
  unsigned long startOfPreheating = millis(); //akutelle Laufzeit des Microcontrollers speichern.
  Serial.print("Heize den Sensor vor... Aktuelle Laufzeit: ");
  Serial.print(startOfPreheating);
  Serial.println(" ms.");
  LED_off(); // LED wieder aus
  digitalWrite(LED_red, LOW); //Nur Rot bleibt an
  lcd.clear();
  while ((millis() < 900000) && (skipPreheating == false)) {
    int millis100pressed = 0; // Für das Überspringen der Vorheizphase Zählervariable initalisieren
    int prozentwert = (millis() / 9000); //Prozentwert der Vorheizzeit berechnen.
    Serial.print("Der Sensor heizt seit ");
    Serial.print(millis());
    Serial.print(" ms vor, das sind ");
    Serial.print(prozentwert);
    Serial.println(" % der Vorheizphase");
    delay(1000);
    lcd.setCursor(0, 0); //Prozentwert auf das LCD Plotten
    lcd.print("Vorheizen: ");
    lcd.print(prozentwert);
    lcd.print(" %");
    LCD_Draw(prozentwert); // Die Funktion "LCD_Draw" Aufrufen
    while (buttonvalue() == true) { //Wenn der Button gedrückt ist, wird in diese Funktion gegeangen
      Serial.println("Knopf gedrückt!");
      millis100pressed++;
      delay(100);
      if (millis100pressed >= 30) {
        Serial.println("Knopf 4 Sekunden am Stück gedrückt, überspringe Vorwärmen.");
        lcd.clear();
        lcd.setCursor(0, 0);
        lcd.print("\365berspringe"); //Überspringe mit \365 als Ü kodiertem Charakter
        lcd.setCursor(0, 1);
        lcd.print("Vorheizen!");
        digitalWrite(LED_red, HIGH); //Die auf Grün umschalten
        digitalWrite(LED_green, LOW);
        delay(1500);
        skipPreheating = true;
        break;
      }
    }
  }
  lcd.clear();
  digitalWrite(LED_red, HIGH); //alle LED-Pins auf "HIGH" setzten, so ist die LED aus.
}

bool buttonvalue() { // Diese Schleife wandelt den analogen Wert des Knopfes in einen wahr/unwahr-Wert um.
  if (analogRead(buttonPin) < 512) return true;
  else return false;
}

void LED_off() {
  digitalWrite(LED_red, HIGH); // LED wieder aus
  digitalWrite(LED_green, HIGH);
  digitalWrite(LED_blue, HIGH);
}

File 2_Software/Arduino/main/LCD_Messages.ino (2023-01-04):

void LCD_Startup() { //Die LED-Startup-Anzeige
  Serial.println("Starte das OSAMD-Projekt!");
  digitalWrite(LED_green, LOW);
  lcd.clear();
  lcd.setCursor(2, 0);
  lcd.print("Starte OSAMD");
  lcd.setCursor(4, 1);
  lcd.print("V. 1.2A");
  delay(2500);
  digitalWrite(LED_green, HIGH);
  digitalWrite(LED_blue, LOW);
  lcd.clear();
  lcd.setCursor(0, 0);
  lcd.print("Heize Sensor,");
  lcd.setCursor(0, 1);
  lcd.print("Dauer: 15 Min.");
  delay(2500);
  digitalWrite(LED_green, LOW);
  digitalWrite(LED_blue, LOW);
  digitalWrite(LED_red, LOW);
  lcd.clear();
  lcd.setCursor(0, 0);
  lcd.print("\365berspringen:"); //Überspringen mit \365 als Ü kodiertem Charakter
  lcd.setCursor(0, 1);
  lcd.print("3 Sek. Dr\365cken"); // Drücken
  delay(3500);
}

void LCD_Config() {
  int millis100pressed = 0; // Zählervariable für Knopfdruck initalisieren
  unsigned int countertrybutton = 0; //Diese Variable spreichert, wie häufig bereits geprüft wurde, ob der Knopf schon gedrückt wurde.
  bool buttonpressed = false;
  bool buttonpressedlong = false;
  bool changevalue = false;
  Serial.println("Knopf 4 Sekunden am Stück gedrückt");
  lcd.clear();
  if (buzzer_active == true) {
    tone(buzzer, 440);
    delay(300);
    noTone(buzzer);
  }
  lcd.setCursor(0, 0);
  lcd.print("Konfigurations-");
  lcd.setCursor(0, 1);
  lcd.print("Assistent");
  digitalWrite(LED_blue, LOW); //Die auf Blau umschalten
  delay(2700);
  lcd.clear();
  lcd.setCursor(0, 0);
  lcd.print("Hinweist\357ne:"); //Hinweistöne, mit Umlaut als \357 kodiert
  lcd.setCursor(0, 1);
  if (buzzer_active == true) lcd.print("Aktiviert");
  else lcd.print("Stumm");
  while ((countertrybutton <= 200) && (buttonpressedlong == false)) {
    delay(100);
    countertrybutton++;
    Serial.println(countertrybutton);
    while ((buttonvalue() == true) && (buttonpressedlong == false)) { //Wenn der Button gedrückt ist, wird in diese Funktion gegangen
      countertrybutton = 0; //Die Zählervariable wieder auf 0
      Serial.println("Knopf gedrückt!");
      millis100pressed++;
      delay(100);
      if (millis100pressed >= 25) {
        buttonpressedlong = true;
      }
      else {
        changevalue = true;
      }
    }
    if ((buttonpressedlong == false) && (changevalue == true)) {
      changevalue = false;
      millis100pressed = 0;
      buzzer_active = !buzzer_active;
      Serial.println("Invertiere button_active.");
      lcd.clear();
      lcd.setCursor(0, 0);
      lcd.print("Hinweist\357ne:"); //Hinweistöne, mit Umlaut als \357 kodiert
      lcd.setCursor(0, 1);
      if (buzzer_active == true) lcd.print("Aktiviert");
      else lcd.print("Stumm");
    }
  }
  if (buttonpressedlong == false) {
    return;
  }
  buttonpressedlong = false; // Die Variablen wieder zurücksetzen.
  countertrybutton = 0;
  millis100pressed = 0;
  //Menü 2: Hintergrundbeleuchtung
  lcd.clear();
  lcd.setCursor(0, 0);
  lcd.print("Displaylicht:"); //Hinweistöne, mit Umlaut als \357 kodiert
  lcd.setCursor(0, 1);
  if (I2C_backlight == true) lcd.print("Eingeschaltet");
  else lcd.print("Ausgeschaltet");
  Serial.println("Menü: Hintergrundbeleuchtung");
  while ((countertrybutton <= 200) && (buttonpressedlong == false)) {
    Serial.println("loop");
    delay(100);
    countertrybutton++;
    Serial.println(countertrybutton);
    while ((buttonvalue() == true) && (buttonpressedlong == false)) { //Wenn der Button gedrückt ist, wird in diese Funktion gegangen
      countertrybutton = 0; //Die Zählervariable wieder auf 0
      Serial.println("Knopf gedrückt!");
      millis100pressed++;
      delay(100);
      if (millis100pressed >= 25) {
        buttonpressedlong = true;
      }
      else {
        changevalue = true;
      }
    }
    if ((buttonpressedlong == false) && (changevalue == true)) {
      changevalue = false;
      millis100pressed = 0;
      I2C_backlight = !I2C_backlight;
      Serial.println("Invertiere I2C_backlight.");
      lcd.clear();
      lcd.setCursor(0, 0);
      lcd.print("Displaylicht:"); //Hinweistöne, mit Umlaut als \357 kodiert
      lcd.setCursor(0, 1);
      if (I2C_backlight == true) {
        lcd.backlight();
        lcd.print("Eingeschaltet");
      }
      else {
        lcd.noBacklight();
        lcd.print("Ausgeschaltet");
      }
    }
  }
  if (buttonpressedlong == false) {
    return;
  }
  buttonpressed = false; // Die Variablen wieder zurücksetzen.
  countertrybutton = 0;
  EEPROM.write(0, buzzer_active);
  EEPROM.write(1, I2C_backlight);
}

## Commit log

2020-11-09 Small corrections in tabulation
    [main.ino]
2020-11-26 LED-Test hinzugefügt und weitere Fortschritte im Hauptprogramm
2020-11-26 Prozessleiste bug behoben und Prozentanzeige für Vorheitzen hinzugefügt
    [I2C_Chars.ino, main.ino]
2020-11-27 Begonnen, die Hauptschleife auszuarbeiten
2020-11-28 Umlaute hinzugefügt (Kodiert als z.B. \365) und weitere Menüausarbeitung
2020-11-29 Weitere Menüverbesserungen, Bugs behoben in der Hauptschleife
    [LCD_Messages.ino, main.ino]
2020-11-29 Zweites Menü eingefügt, Fehlerbehebungen und früheres Einlesen von den Variablen
2020-11-29 Fehlerbehebungen
    Einen Fehler behoben, bei dem der Buzzer trotz Stummschaltung noch gepiepst hat.
    [LCD_Messages.ino]
2020-12-06 PCB-Dateien hinzugefügt
2020-12-06 STL-Gehäusedateien Hinzugefügt
    Version 2.0 der Dateien
    [Enclosure_PART-A.stl, Enclosure_PART-B.stl]
2020-12-06 BOM Added.
    [BOM.xlsx]
2020-12-06 Stromkabel auf BOM hinzugefügt
    [BOM.xlsx]
2020-12-06 Bilder hinzugefüt und Prozentwerte im Hauptprogramm verändert
2020-12-06 Weiter an der Doku geschrieben
2020-12-06 Bild des Knopfes hinzugefügt.
2020-12-06 Rechtschreibfehler korrigiert und Bild hinzugefügt.
2020-12-06 Video in die Readme hinzugefügt.
2021-03-31 Kleine Typingfixes und eine spezifizierung der LED-Position
    Danke an @AlexWerz für den Hinweis der ungenauen LED-Beschreibung!
    [BOM.xlsx]
2021-03-31 Reverted progress bar (bad air is smaller bar), raised the max value to 768, commented about the lib used for LCD, change lcd.begin to lcd.init
    [I2C_Chars.ino, main.ino]
2021-04-01 Neue PCB Version 2.1
    Es wurde verbessert, wie der Kontrast des Displays eingestellt werden kann: Jetzt gibt es ein Loch durch die Leiterplatte, mit dem auch bei verlötetem Display der Kontrast nachgestellt werden kann.
2023-01-04 started implementation of DHT temperature sensor series, version bump
2023-01-04 first (wanky) implementation of dht sensor
2023-01-04 Stable implementation of DHT Temperature probe, general bugfixes & more documentation :100:
    [LCD_Messages.ino, main.ino]
2023-01-04 added pcb source files for issue #2
    [altium_LCD-v2.pcbdoc]
2023-01-08 Hotfix fixing non-display on tempprobe not connected
    [main.ino]
